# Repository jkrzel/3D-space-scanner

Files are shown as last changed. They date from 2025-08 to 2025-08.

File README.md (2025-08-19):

# 3D-space-scanner
A scanning device that uses ultrasound distance sensor (HC-SR04) to create a 3D plot of the scanned area.

  The project is mainly focused on creating short distance obstacle detection for moving robots. The ultrasound sensor is not the best option for creating a 3D scanning device becouse of the complications associated with
ultrasound beam. The echo is usually lost on longer distances or is being wrongly bounced off the more complicated surfaces. However this project is a great base for developement of more accurate scan devices
using laser distance sensors.
  The device is able to create a 3D plot with visible obstacles in range of 200 cm thanks to the movement mechanism of two micro servos (SG-90). The servos provide movement of the sensor in Yaw Axis (0 deg - 180 deg)
and in Pitch Axis (50 deg - 130 deg). The whole device control system is set on Arduino UNO R3 that transmits every measured distance and the current positions of servos in packets of 6 bytes via UART to a 
Python program that constructs the 3D plot using matplotlib library.

The whole transmission length varies depending on scan accuracy settings in Arduino code but it can be calculated using this formula:

    TRANSMISSION_LENGTH = ( ( (180 / TURN_VALUE) + 1 ) * ( (80 / TURN_VALUE) + 1 ) * 6 ) + 3 [ Bytes ]

  where:
    (180 / TURN_VALUE) + 1 ) * ( (80 / TURN_VALUE) + 1 ) - is the number of expected packets

Packets are constructed as follows
  
Packets consist of 6 bytes: B5 B4 B3 B2 B1 B0, where:
  B5 - Start marker (0xFF)
  B4 - Rotation in x-axis
  B3 - Rotation in y-axis
  B2 - Integer part of distance value
  B1 - Fractional part of distance value
  B0 - End marker (0xFE)
  
Scanner won't continue work until program in Python sends back the ACK message. If the packet byte order has been damaged in any way through the transmission prosses the Python programme will send an NAK 
message to the Arduino to retry the measurement in the same position and send the packet again. This way no packet will be lost in the communication process.

Transmission control messagges:
  START_OF_TRANSMISSION 0xFD      - Marker of a start of a transmission
  END_OF_TRANSMISSION   0xFC      - Marker of an end of a transmission
  START_MARKER          0xFF      - Marking of the start of a packet
  END_MARKER            0xFE      - Marking of an end of a packet
  ACK                   0x06      - Acknowledgement of sent packet
  NAK                   0x15      - Negative-acknowledgement of sent packet ( retry the measurment )

The 3d plot creation process is simply calculating the point coordinates using servo rotation values and vector extention depending on the measured distance.

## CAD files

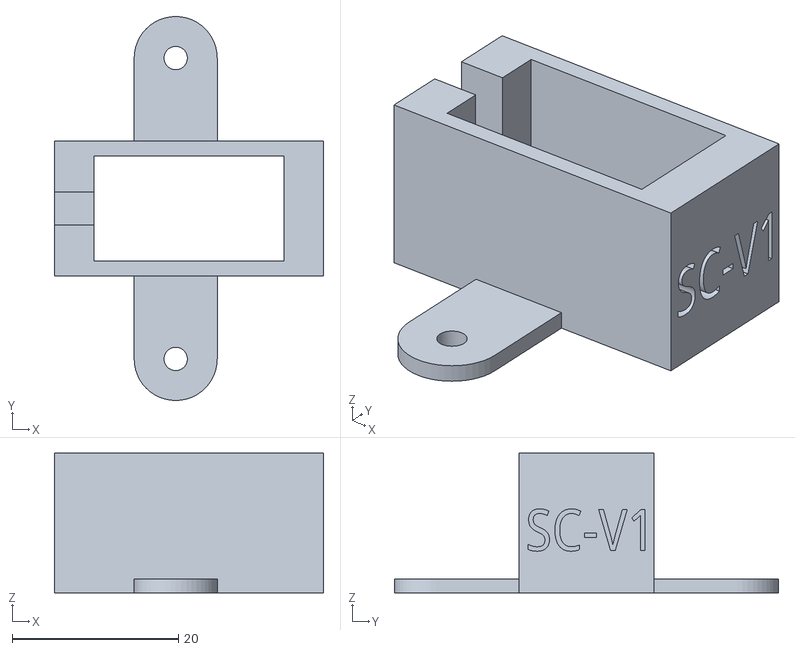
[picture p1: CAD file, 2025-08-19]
Scaner stl files/servo1_mount.stl
32.4 x 46.2 x 16.8

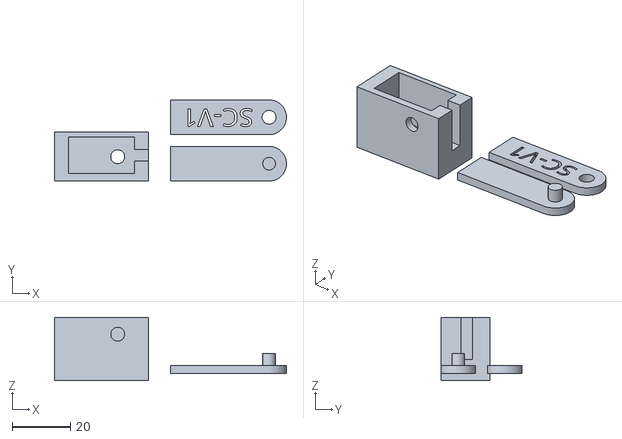
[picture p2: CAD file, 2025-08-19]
Scaner stl files/servo2_mount.stl
80.0 x 28.0 x 21.8

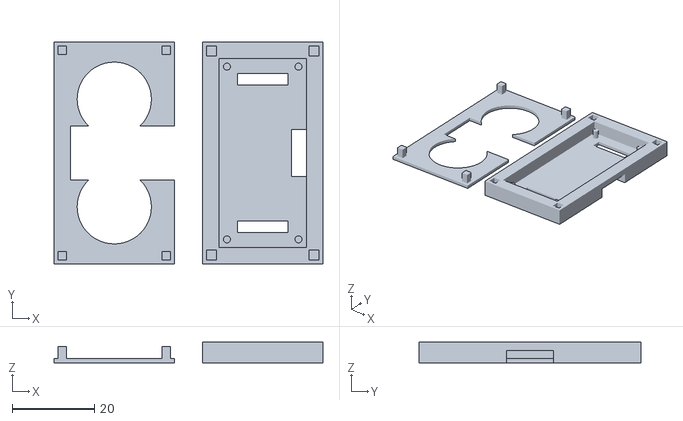
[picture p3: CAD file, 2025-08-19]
Scaner stl files/HC-SR04_mount.stl
65.2 x 53.8 x 5.00

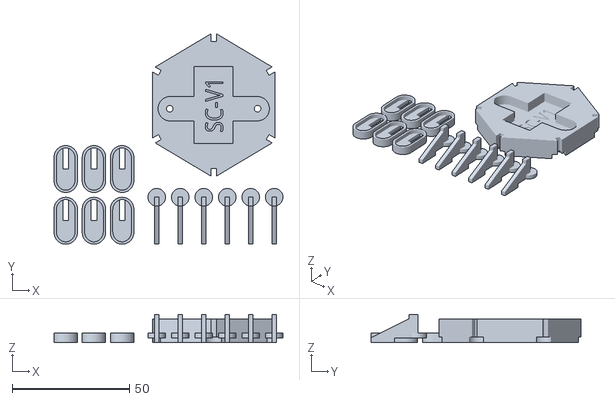
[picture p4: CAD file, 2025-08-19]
Scaner stl files/scanner_foot.stl
97.5 x 89.6 x 12.0

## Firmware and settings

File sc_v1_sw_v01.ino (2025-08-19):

#include <LiquidCrystal_I2C.h>
#include <Wire.h>
#include <Servo.h>

// Transmission control messages
#define START_OF_TRANSMISSION 0xFD      // Marker of a start of a transmission
#define END_OF_TRANSMISSION   0xFC      // Marker of an end of a transmission
#define START_MARKER          0xFF      // Marking of the start of a packet
#define END_MARKER            0xFE      // Marking of an end of a packet
#define ACK                   0x06      // Acknowledgement of sent packet
#define NAK                   0x15      // Negative-acknowledgement of sent packet ( retry the measurment )

// Scan accuracy settings
#define N_SAMPLES 5                     // Number of samples taken from a single measurment
#define TURN_VALUE 10                   // Value of the turns ( in degrees ) taken in a single iteration by the device ( in range (0, 180] )
#define SERVO_DELAY 100                 // Value (in ms) of servo movements delay

// Arduino Uno R3 Pinout
const int trigPin = 6;  
const int echoPin = 11; 
const int servo1Pin = 9;
const int servo2Pin = 10;
const int startScanButtonPin = 2;

Servo servo1;
Servo servo2;
LiquidCrystal_I2C lcd(0x27, 16, 2);
const int pos1 = 180, pos2 = 130;
bool turn = true;
float duration, distance, progress, ser2, complete;

void sortFloats(float arr[], int n) {
  for (int i = 0; i < n - 1; i++) {
    for (int j = 0; j < n - i - 1; j++) {
      if (arr[j] > arr[j + 1]) {
        float temp = arr[j];
        arr[j] = arr[j + 1];
        arr[j + 1] = temp;
      }
    }
  }
}

float measureMedian()
{
  int validCount = 0;
  float distances[N_SAMPLES];
  for(int i = 0; i < N_SAMPLES; i++)
  {
    float d = measureDistance();
    if(d >= 0)
    {
      if(d > 200) distances[validCount++] = 201;
      else distances[validCount++] = d;
    }
    delay(60);
  }
  if(validCount == 0) return -1;
  sortFloats(distances, N_SAMPLES);
  return distances[validCount / 2];
}

float measureDistance()
{
  digitalWrite(trigPin, LOW);  
  delayMicroseconds(2);  
  digitalWrite(trigPin, HIGH);  
  delayMicroseconds(10);  
  digitalWrite(trigPin, LOW); 

  return (pulseIn(echoPin, HIGH, 20000) * 0.0343) / 2;
}

bool sendData(int x_rotation, int y_rotation, float distance)
{
  //packets consist of 6 bytes: B5 B4 B3 B2 B1 B0, where:
  //B5 - Start marker (0xFF)
  //B4 - Rotation in x-axis
  //B3 - Rotation in y-axis
  //B2 - Integer part of distance value
  //B1 - Fractional part of distance value
  //B0 - End marker (0xFE)
  //Scanner won't continue work until program in Python sends back the ACK message

  byte x_rot = byte(x_rotation);
  byte y_rot = byte(y_rotation);
  byte distInt = byte(distance);
  byte distFrac = byte(((distance - distInt) * 100));

  Serial.write(START_MARKER);
  Serial.write(x_rot);
  Serial.write(y_rot);
  Serial.write(distInt);
  Serial.write(distFrac);
  Serial.write(END_MARKER);

  while (true) 
  {
    if (Serial.available()) 
    {
      byte response = Serial.read();
      if (response == ACK) return true;
      else if(response == NAK) return false;
    }
  }
}

void setup() {
  // put your setup code here, to run once:
  Serial.begin(115200);

  lcd.init();    
  lcd.backlight();  
  lcd.setCursor(0, 0);
  lcd.print("");

  pinMode(startScanButtonPin, INPUT_PULLUP);

  pinMode(trigPin, OUTPUT);  
	pinMode(echoPin, INPUT);

  servo1.attach(servo1Pin);
  servo2.attach(servo2Pin);

  servo1.write(pos1);
  servo2.write(pos2);
}

void loop() {
  if(digitalRead(2) == LOW)
  {
    ser2 = 0;
    complete = ((180 / TURN_VALUE) + 1) * ((80 / TURN_VALUE) + 1);
    lcd.setCursor(0, 0);
    lcd.print("Start scan...");
    delay(2000);
    lcd.clear();
    lcd.print("Scanning...");

    Serial.write(START_OF_TRANSMISSION);
    Serial.write(TURN_VALUE);

    for(int i = 130; i >= 50; i -= TURN_VALUE)
    {
      servo2.write(i);
      delay(SERVO_DELAY);

      if(turn){
        for(int j = 180; j >= 0; j -= TURN_VALUE)
        {
          servo1.write(j);
          ser2++;
          progress = (ser2 * 100) / complete;
          lcd.setCursor(0, 1);
          lcd.print("             ");
          lcd.setCursor(2, 1);
          lcd.print(String(int(progress)) + "%");
          delay(SERVO_DELAY);
          while(!sendData(j, i, measureMedian()));
        }
        turn = !turn;
      } 
      else
      {
        for(int j = 0; j <= 180; j += TURN_VALUE)
        {
          servo1.write(j);
          ser2++;
          progress = (ser2 * 100) / complete;
          lcd.setCursor(0, 1);
          lcd.print("           ");
          lcd.setCursor(2, 1);
          lcd.print(String(int(progress)) + "%");
          delay(SERVO_DELAY);
          while(!sendData(j, i, measureMedian()));
        }
        turn = !turn;
      }

      Serial.write(END_OF_TRANSMISSION);
    }
    servo1.write(pos1);
    servo2.write(pos2);
    lcd.clear();
    lcd.print("Scan complete.");
    delay(2000);
    lcd.clear();
  }
}

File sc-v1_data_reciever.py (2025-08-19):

import serial
import matplotlib.pyplot as plt
import numpy as np
from scipy.interpolate import griddata

serialPort = serial.Serial('COM6', 115200, timeout=1)

START_OF_TRANSMISSION = 0xFD        # marker of a start of a transmission
END_OF_TRANSMISSION = 0xFC          # marker of an end of a transmission
START_MARKER = 0xFF                 # marker of a start of a packet
END_MARKER = 0xFE                   # marker of an end of a packet
ACK = 0x06                          # marker of correct packet
NAK = 0x15                          # marker of incorrect packet

radius = 4.0                        # radius of movement of sensor in both axis
max_dist = 200.0                    # maximal range of sensor (HC-SR04)

raw_points = []                     # all collected points

def read_full_packet(n_packets):
    i = 0
    while i < n_packets:
        byte_in = serialPort.read(1)

        if not byte_in:
            serialPort.write(bytes([NAK]))
            i -= 1
            continue

        if byte_in[0] != START_MARKER:
            serialPort.write(bytes([NAK]))
            i -= 1
            continue

        data = serialPort.read(5)  # X, Y, distInt, distFrac, END_MARKER
        if len(data) != 5 or data[-1] != END_MARKER:
            serialPort.write(bytes([NAK]))
            i -= 1
            continue

        x_rot = data[0] - 90.0
        y_rot = data[1] - 90.0
        d = data[2] + data[3] / 100.0

        raw_points.append((x_rot, y_rot, d))

        serialPort.write(bytes([ACK]))
        i += 1


while True:
    first_byte = serialPort.read(1)
    if not first_byte:
        continue
    if first_byte[0] != START_OF_TRANSMISSION:
        continue

    turn_value = int.from_bytes(serialPort.read(1), "little")
    num_of_packets = ((180 / turn_value) + 1) * ((80 / turn_value) + 1)

    print("Start of transmission.")

    read_full_packet(num_of_packets)

    last_byte = serialPort.read(1)
    if last_byte[0] == END_OF_TRANSMISSION:
        print("End of transmission.")
        break


serialPort.close()

raw_points = np.array(raw_points)
yaw_measured = raw_points[:, 0]
pitch_measured = raw_points[:, 1]
dist_measured = raw_points[:, 2]

grid_yaw, grid_pitch = np.meshgrid(
    np.linspace(yaw_measured.min(), yaw_measured.max(), 200),
    np.linspace(pitch_measured.min(), pitch_measured.max(), 200)
)

mask = dist_measured > 0

grid_distances = griddata(
    (yaw_measured[mask], pitch_measured[mask]),
    dist_measured[mask],
    (grid_yaw, grid_pitch),
    method='linear',
    fill_value=max_dist
)

grid_distances[0, :] = max_dist
grid_distances[-1, :] = max_dist
grid_distances[:, 0] = max_dist
grid_distances[:, -1] = max_dist

X = grid_distances * np.cos(np.deg2rad(grid_pitch)) * np.cos(np.deg2rad(grid_yaw))
Y = grid_distances * np.cos(np.deg2rad(grid_pitch)) * np.sin(np.deg2rad(grid_yaw))
Z = grid_distances * np.sin(np.deg2rad(grid_pitch))

fig = plt.figure(figsize=(10, 7))
ax = fig.add_subplot(111, projection="3d")
surf = ax.plot_surface(X, Y, Z, cmap="viridis", linewidth=0, antialiased=True)

ax.set_xlabel("X [cm]")
ax.set_ylabel("Y [cm]")
ax.set_zlabel("Z [cm]")
plt.title("Scan 3D")
plt.show()
